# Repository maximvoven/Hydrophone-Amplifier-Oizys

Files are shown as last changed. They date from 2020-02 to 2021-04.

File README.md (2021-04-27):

# Project OizysAMP

**Designer**: Maxim Vovenko

## Warning:
This was designed in High School for a club called AVBotz, this work predates my studies of EE at San Jose State University. Reuse Design at your own peral, Im not responsible for anything that happens or gurentee this works. This is only stored for historical record.

## Description:
This is the Hydrophone Amplifier Code name "Oizys". The code name reflects the absord amount of time 
figuring out how to make the amplifier and the amount of rivisions that have been trashed. This is the 
First version of the amplifer wich has been designed based on reasearch and simulations run in LTSpice
by Analog Devices. Oziys board is a three stage amplifier and filter combo witch has been tunned to
filter out signals below 20khz and above 55khz. The recommended sample rate is above 200khz. The board
Consists of three stages each one is powered by an ad8676 dual channel opamp. Dual channel opamps were
selected due to the relative little cross talk they have and there ability to process two signals at a
time. Stage one is a preamp/decoupling stage witch is required due to the use of piezoelectric 
Hydrophones. A 1 giga ohm resistor is used to stabalize and prevent saturation of the piezoelectric 
element. Stage two is an amp stage with the ability to be set to static out-put or variable output by 
selecting weather you use resistors R2A/R2B or trimpots vr1/vr2 respectively. Stage 3 is an anti-aliasing 
filter prioritizing speed over atenuation. There is a final passive stage wich offsets the signal by 1.64v 
using a high pass filter with ground replaced by 1.64v. The amp is to be tuned to function within 0-3.3v.
Resources used to build this design are included and so is a BOM.

While the material distrubuted with the mit license I can not and do not take credit for any work done except
for the following files: HydrophoneAmpliferCircuit.sch, HydrophoneAmpliferCircuit.brd, README.md, BOM.ods,AmpV0.asc
the files listed above are as a result of my work and are as a result covered under MIT License.

## Software Used: 
Eagle, LTSPICEXVII

## Known Issues:
-Design is suboptimal, the stages for amplification and signal conditioning should be reversed to prevent clipping
-Power Supply instantly fails under _any_ transient voltage spikes.
-Improper Crimping may result in damage to power supply due to no reverse polarity protection being present and software engineers not being able to decode wire coloring.
-The reference voltage is coupled to the signal producing artifacts in the signal, this needs to be decoupled.
-Gain calculations may be off by factor of 10, recalculation required (Symptoms: Signal observed to be in 10mv range instead of 1v).

## Revision History:
V1.2
-Updated License
-OpenSourced with MIT License
-Updated Silkscreens to reflect new state of the project.

V1.1
-Miscillaneous changes
-Moved around silkscreen for ease of assembly
-DRC Check Cleared
-Added OshaPark DRC

V1.0
-Finalized Schematic
-Created and finalized board layout and traces.
-Created Silk Screens.

V0.3
-Finalized Schematic
-Updated Library With Necessary Componets
-Organized BRD slightly before building final board

V0.2
-Semi-final design
-LTspiceXVII Simulation Files Added
-1.6V Rail Created 
-1.6v Filtering added using 1uf
-Identified resistor to replace with pot
TODO:
-Calculate Amplifier Circuit to add calibration ability
-Add C Filtering to 24v rail
-Add C Filter 12v
-Add C Filter -12v 

V0.1.1
-Renamed to  "Project OizysAMP"
-Updated Capcitors In Filtering circuit to accuratly reflect components being installed
-Lost hope in humanity
-Wished that power supply filtering was as easy as it is to say power supply filtering

V0.1
Initial Incomplete design
-Missing Power supply filtering
-missing connectors
-Missing Board Design
-missing design constraints
-Completed amplyfiying circuit
-Missing trim pot for tuning amp circuit
-Testpoints were added to faciilitate diagnostics.

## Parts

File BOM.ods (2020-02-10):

Part | Source | Type | Cost | quantity
0.1uf bypass | https://www.mouser.com/ProductDetail/Yageo/CC0603JPX7R9BB104 | Bypass Smd Cap | 0.13 | 6
330pf | https://www.mouser.com/ProductDetail/81-RDE5C3A331J2M1H3A | Axial/Radial | 0.68 | 2
3.3nf | https://www.mouser.com/ProductDetail/810-FA24NP2E332JNU06 | Axial/Radial | 0.46 | 2
1.6nf | https://www.mouser.com/ProductDetail/80-C320C162JDG | Axial/Radial | 1.81 | 2
10uf Capacitor | https://www.mouser.com/ProductDetail/WIMA/MKS2B051001N00MSSD?qs=sGAEpiMZZMv1cc3ydrPrF7l45uRd9dVhmlRkbdCicHg%3D | Radial Film Cap | 2.42 | 3
191ohm | https://www.mouser.com/ProductDetail/Vishay-BC-Components/SFR16S0001910FR500 | Standard Axial | 0.12 | 1
330ohm Resistor Axil | ResistorBible | Standard Axial | n/a | 2
680ohm | ResistorBible | Standard Axial | n/a | 2
1k resistor axil | ResistorBible | Standard Axial | n/a | 2
1.2kohm | https://www.mouser.com/ProductDetail/Vishay-Dale/CPF21K2000FKE14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 | Standard Axial | 0.9 | 1
10k | ResistorBible | Standard Axial | n/a | 2
10k trimpot | https://www.mouser.com/ProductDetail/SparkFun/COM-09806 | TrimPot | 0.9 | 2 | replace 1k resistor
22k | ResistorBible | Standard Axial | n/a | 2
1g ohm | https://www.mouser.com/ProductDetail/TE-Connectivity-Neohm/RGP0207CHK1G0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 | Standard Axial? | 0.66 | 2
+12v Coverter from 24v | https://www.mouser.com/ProductDetail/MEAN-WELL/DPU01N-12 | Custom Library | 3.06 | 1
3xAD8676ARZ | https://www.mouser.com/ProductDetail/Analog-Devices/AD8676ARZ-REEL | ARZ | 4.31 | 3 | Backorder End May
 |  |  | 34.07

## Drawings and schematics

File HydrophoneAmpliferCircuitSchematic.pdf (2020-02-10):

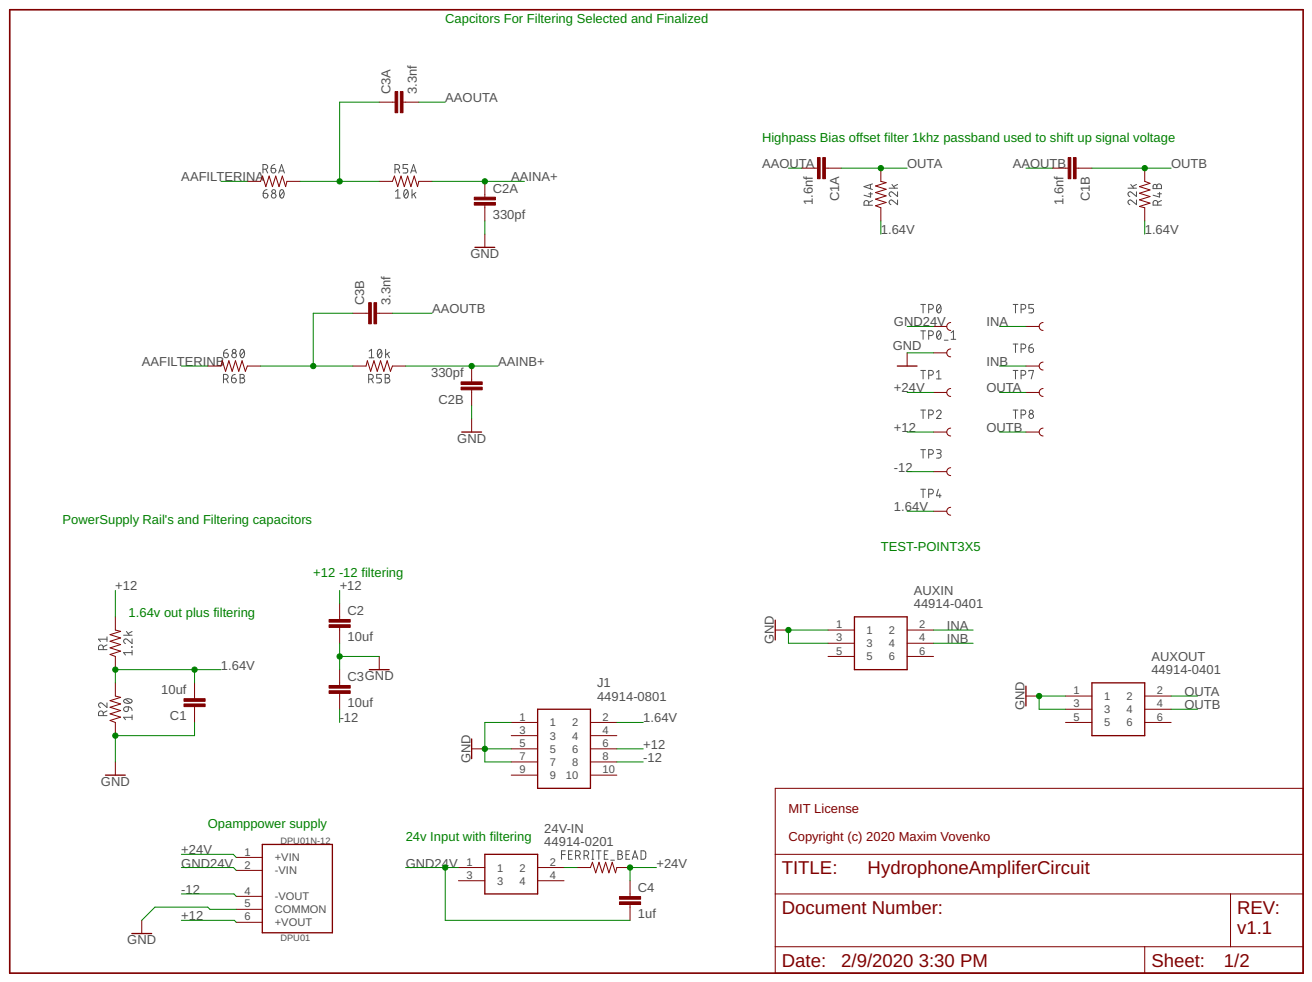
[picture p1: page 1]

Capcitors For Filtering Selected and Finalized

Highpass Bias offset filter 1khz passband used to shift up signal voltage

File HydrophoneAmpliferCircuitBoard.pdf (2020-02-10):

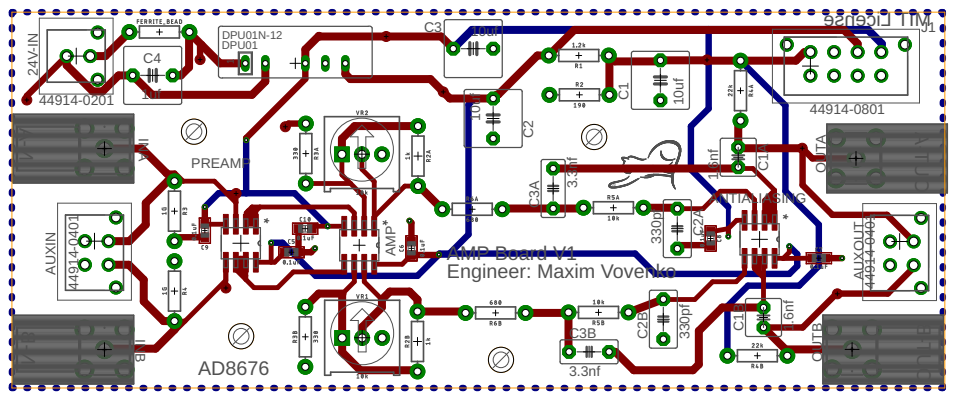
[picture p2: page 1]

esneci L TI MOUT-A OUT-B IN-A IN-B V M AMP Board V1 Engineer: Maxim Vovenko 44914-0201 ** 1uf * 1 ** AD8676 24V-IN AMP ANTIALIASING AUXIN 44914-0401 AUXOUT 44914-0401 C1 10uf C1A 1.6nf C1B 1.6nf C210uf C2A 330pf C2B 330pf C3 10uf C3A3.3nf C3B 3.3nf C4 J1 44914-0801 PREAMP INA INB OUTA OUTB DPU01N-12 DPU01

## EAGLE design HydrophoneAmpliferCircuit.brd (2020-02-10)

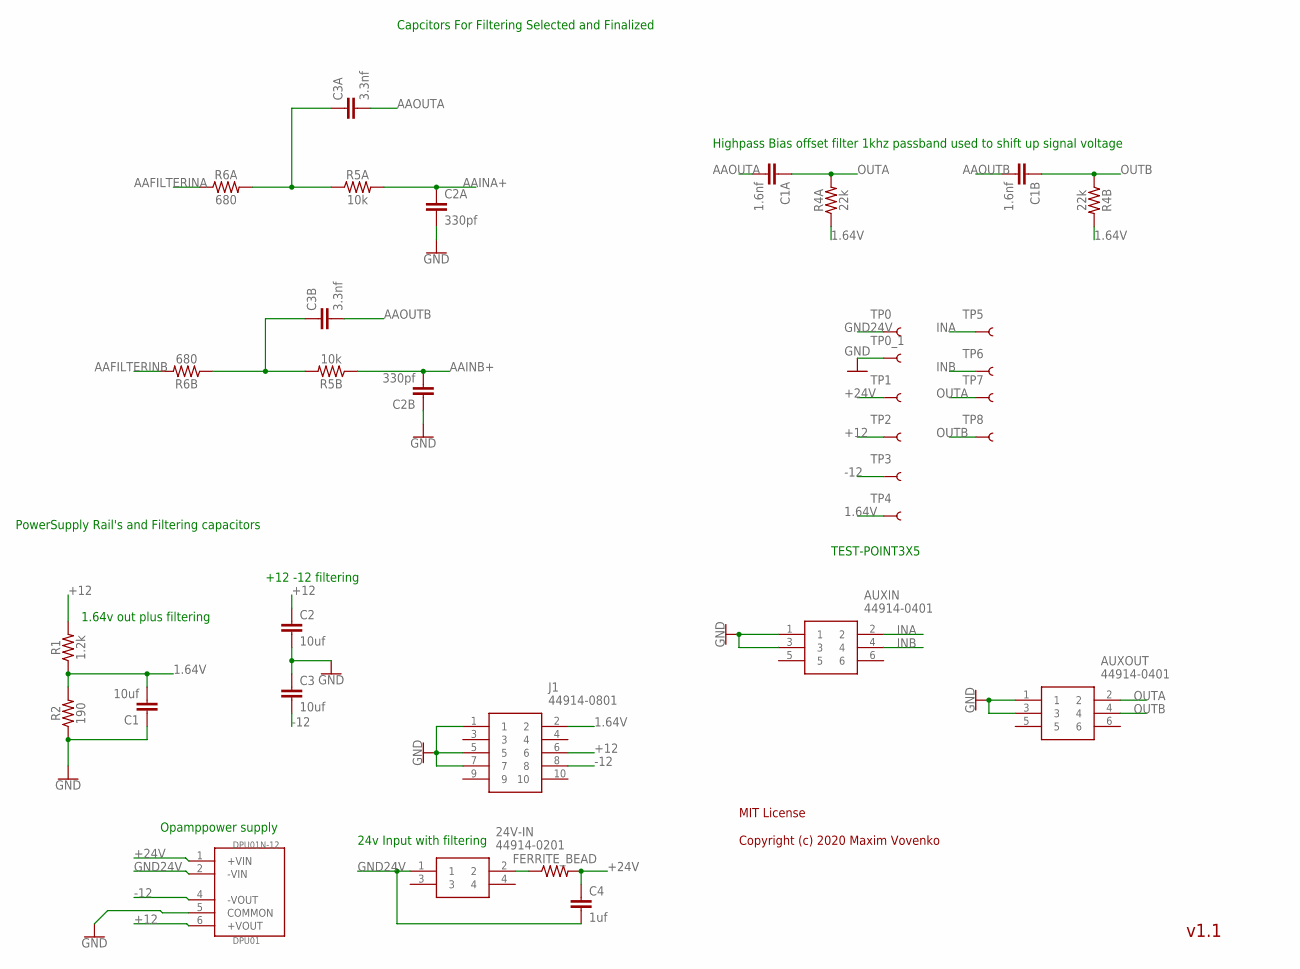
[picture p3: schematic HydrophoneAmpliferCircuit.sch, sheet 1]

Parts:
24V-IN: 44914-0201; 449140201
AUXIN: 44914-0401; 449140401
AUXOUT: 44914-0401; 449140401
C1, C2, C3: 10uf; C5B7.2
C1A, C1B: 1.6nf; C2.5-5
C2A, C2B: 330pf; C5B3.5
C3A, C3B: 3.3nf; C5B3
C4: 1uf; C5B7.2
DPU01N-12: DPU01
FERRITE_BEAD: AXIAL-0.3
J1: 44914-0801; 449140801
R1: 1.2k; AXIAL-0.3
R2: 190; AXIAL-0.3
R4A, R4B: 22k; AXIAL-0.3
R5A, R5B: 10k; AXIAL-0.3
R6A, R6B: 680; AXIAL-0.3
TP0, TP0_1, TP1, TP2, TP3, TP4, TP5, TP6, TP7, TP8: TEST-POINT3X5; PAD.03X.05

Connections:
1.64V: C1.2, J1.2, R1.P$1 (1), R2.P$2 (2), R4A.P$1 (1), R4B.P$2 (2), TP4.P$1
+12: C2.1, DPU01N-12.6 (+VOUT), J1.6, R1.P$2 (2), TP2.P$1; also elsewhere on the board
+24V: C4.1, DPU01N-12.1 (+VIN), FERRITE_BEAD.P$2 (2), TP1.P$1
-12: C3.2, DPU01N-12.4 (-VOUT), J1.8, TP3.P$1; also elsewhere on the board
AAFILTERINA: R6A.P$1 (1); also elsewhere on the board
AAFILTERINB: R6B.P$2 (2); also elsewhere on the board
AAINA+: C2A.1, R5A.P$2 (2); also elsewhere on the board
AAINB+: C2B.2, R5B.P$1 (1); also elsewhere on the board
AAOUTA: C1A.2, C3A.2; also elsewhere on the board
AAOUTB: C1B.2, C3B.2; also elsewhere on the board
GND: AUXIN.1, AUXIN.3, AUXOUT.1, AUXOUT.3, C1.1, C2.2, C2A.2, C2B.1, C3.1, DPU01N-12.5 (COMMON), J1.1, J1.5, J1.7, R2.P$1 (1), TP0_1.P$1; also elsewhere on the board
GND24V: 24V-IN.1, C4.2, DPU01N-12.2 (-VIN), TP0.P$1
INA: AUXIN.2, TP5.P$1; also elsewhere on the board
INB: AUXIN.4, TP6.P$1; also elsewhere on the board
unnamed: C3B.1, R5B.P$2 (2), R6B.P$1 (1)
unnamed: 24V-IN.2, FERRITE_BEAD.P$1 (1)
unnamed: C3A.1, R5A.P$1 (1), R6A.P$2 (2)
OUTA: AUXOUT.2, C1A.1, R4A.P$2 (2), TP7.P$1; also elsewhere on the board
OUTB: AUXOUT.4, C1B.1, R4B.P$1 (1), TP8.P$1; also elsewhere on the board

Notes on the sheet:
Capcitors For Filtering Selected and Finalized
Highpass Bias offset filter 1khz passband used to shift up signal voltage
Opamppower supply
PowerSupply Rail's and Filtering capacitors
TEST-POINT3X5
24v Input with filtering
+12 -12 filtering
1.64v out plus filtering
v1.1
MIT License Copyright (c) 2020 Maxim Vovenko

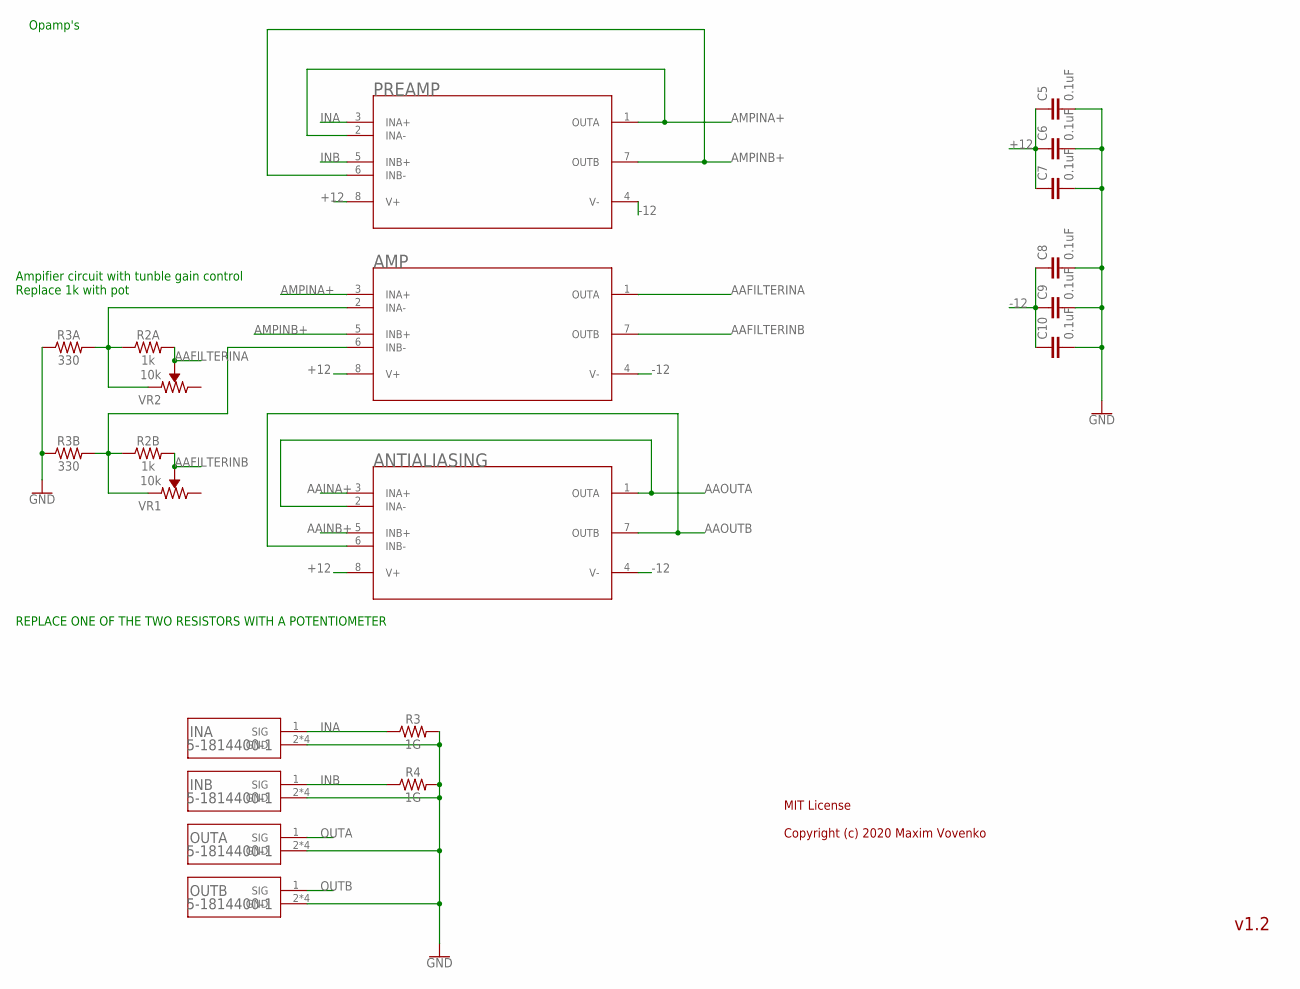
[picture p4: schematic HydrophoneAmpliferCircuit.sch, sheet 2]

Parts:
AMP: AD8676ARZR_8-M; R_8-M
ANTIALIASING: AD8676ARZR_8-M; R_8-M
C5, C6, C7, C8, C9, C10: 0.1uF; 0603
INA: 5-1814400-1
INB: 5-1814400-1
OUTA: 5-1814400-1
OUTB: 5-1814400-1
PREAMP: AD8676ARZR_8-M; R_8-M
R2A, R2B: 1k; AXIAL-0.3
R3, R4: 1G; AXIAL-0.3
R3A, R3B: 330; AXIAL-0.3
VR1, VR2: 10k; TRIMPOT-PTH-3386U

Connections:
+12: AMP.8 (V+), ANTIALIASING.8 (V+), C5.1, C6.1, C7.1, PREAMP.8 (V+); also elsewhere on the board
-12: AMP.4 (V-), ANTIALIASING.4 (V-), C8.1, C9.1, C10.1, PREAMP.4 (V-); also elsewhere on the board
AAFILTERINA: AMP.1 (OUTA), R2A.P$2 (2), VR2.2 (WIPER); also elsewhere on the board
AAFILTERINB: AMP.7 (OUTB), R2B.P$2 (2), VR1.2 (WIPER); also elsewhere on the board
AAINA+: ANTIALIASING.3 (INA+); also elsewhere on the board
AAINB+: ANTIALIASING.5 (INB+); also elsewhere on the board
AAOUTA: ANTIALIASING.1 (OUTA), ANTIALIASING.2 (INA-); also elsewhere on the board
AAOUTB: ANTIALIASING.6 (INB-), ANTIALIASING.7 (OUTB); also elsewhere on the board
AMPINA+: AMP.3 (INA+), PREAMP.1 (OUTA), PREAMP.2 (INA-)
AMPINB+: AMP.5 (INB+), PREAMP.6 (INB-), PREAMP.7 (OUTB)
GND: C5.2, C6.2, C7.2, C8.2, C9.2, C10.2, INA.2 (GND), INA.3 (GND), INA.4 (GND), INA.5 (GND), INB.2 (GND), INB.3 (GND), INB.4 (GND), INB.5 (GND), OUTA.2 (GND), OUTA.3 (GND), OUTA.4 (GND), OUTA.5 (GND), OUTB.2 (GND), OUTB.3 (GND), OUTB.4 (GND), OUTB.5 (GND), R3.P$2 (2), R3A.P$1 (1), R3B.P$1 (1), R4.P$2 (2); also elsewhere on the board
INA: INA.1 (SIG), PREAMP.3 (INA+), R3.P$1 (1); also elsewhere on the board
INB: INB.1 (SIG), PREAMP.5 (INB+), R4.P$1 (1); also elsewhere on the board
unnamed: AMP.2 (INA-), R2A.P$1 (1), R3A.P$2 (2), VR2.1 (CCW)
unnamed: AMP.6 (INB-), R2B.P$1 (1), R3B.P$2 (2), VR1.1 (CCW)
OUTA: OUTA.1 (SIG); also elsewhere on the board
OUTB: OUTB.1 (SIG); also elsewhere on the board

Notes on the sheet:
Ampifier circuit with tunble gain control Replace 1k with pot
Opamp's
REPLACE ONE OF THE TWO RESISTORS WITH A POTENTIOMETER
v1.2
MIT License Copyright (c) 2020 Maxim Vovenko

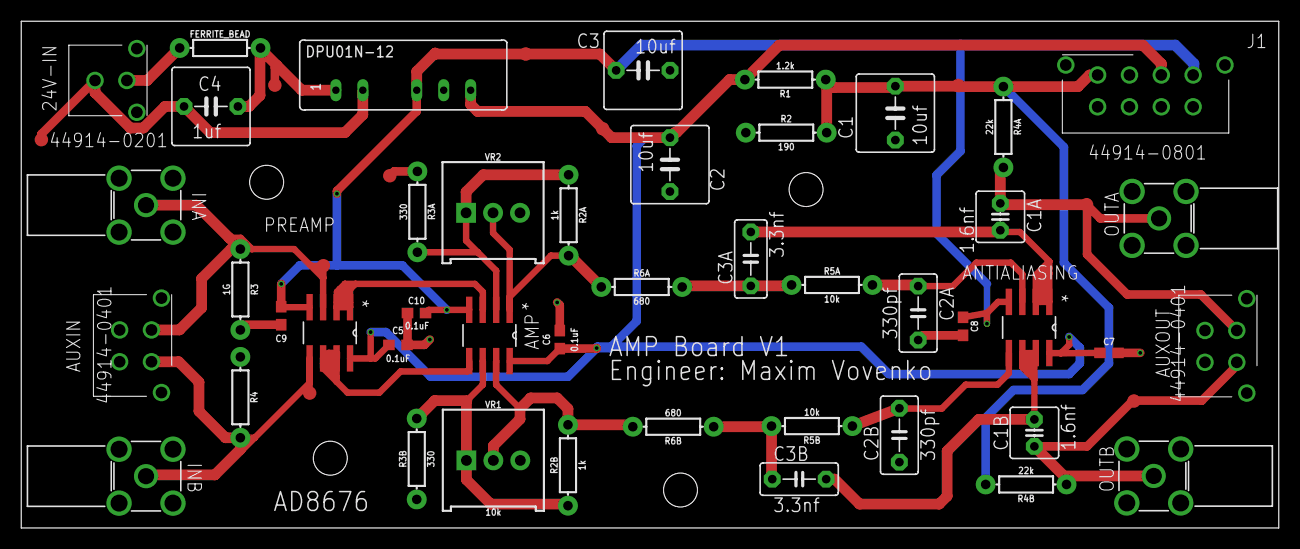
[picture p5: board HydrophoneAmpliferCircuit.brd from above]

Board: 2 copper layers, 118.5 x 47.8 mm, 55 parts (0 on the bottom side), 23 nets.

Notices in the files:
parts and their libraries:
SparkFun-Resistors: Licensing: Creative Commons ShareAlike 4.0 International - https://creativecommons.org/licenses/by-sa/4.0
